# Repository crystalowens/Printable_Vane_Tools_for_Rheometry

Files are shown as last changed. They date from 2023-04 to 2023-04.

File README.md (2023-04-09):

# Printable Vane Tools for Rheometry
Design tools and guidelines for using 3D printable rheometry devices

Please give credit for tools to the appropriate references: 

1\) Improved rheometry of yield stress fluids using bespoke fractal 3D printed vanes  
&emsp;Journal of Rheology 64, 643 (2020); https://doi.org/10.1122/1.5132340   
&emsp;Crystal E. Owens, A. John Hart, and Gareth H. McKinley 

    * for most tools 
    * for the coupling to the rheometer
    * for the cup that mounts to the flat peltier base

2\) Computational rheometry of yielding and viscoplastic flow in vane-and-cup rheometer fixtures  
&emsp;Journal of Non-Newtonian Fluid Mechanics 37, 104857 (2022); https://doi.org/10.1016/j.jnnfm.2022.104857  
&emsp;Emad Chaparian, Crystal E. Owens, and Gareth H. McKinley

    * for the 8-arm tool design 

3\) Time-resolved rheometry of coarsening foams using three-dimensionally printed fractal vanes   
&emsp;Physics of Fluids 34, 113108 (2022); https://doi.org/10.1063/5.0119944  
&emsp;Igor M. Carraretto, Crystal E. Owens, and Gareth H. McKinley

    * for the foaming cup
    * for the cup that slides into the peltier jacket

# Getting started 

See our pdf guide file for general instructions, and see our relevant papers for more detailed instructions  

# Tools included 

In this repository find .stl files for 
* Vanes for DHR-style and AR-style rheometers (tested with DHR-3, AR-G2)  
    * 8-arm fractal vane 
    * 12-arm fractal vane
    * 24-arm fractal vane
    * 4-arm fractal vane 
  
* Cups for DHR-style and AR-style rheometers (tested with DHR-3, AR-G2)
  * Cup base to mount to a flat peltier base, which then accepts a second part, either a cup with a bottom (for viscous fluids) or a cup without a bottom (for yield stress fluids, easier to clean)  
  * One-part cup to slide into a DHR-style peltier jacket
  * Cup for creating foam in-situ, using the 3D printed cup in addition to an airstone and airflow. This is provided in a directly-printable .form file for a Form2 or Form3 printer and also requires printing of the cup base to mount to the rheometer. 
  
* Vanes for ARES-style rheometers (tested with ARES-G2, original ARES)
  * 12-arm fractal for fitting to an ARES coupling. The fitting has been verified but the concentricity of rotation has not 

# Want another tool? 

Please contact me via linkedin or email or open an "issue" on this repository to start a discussion 

# Made your own version of our tools that you want to share? 

Please do! Send me a digital copy and information about why you want to share it and I will add it to our file list

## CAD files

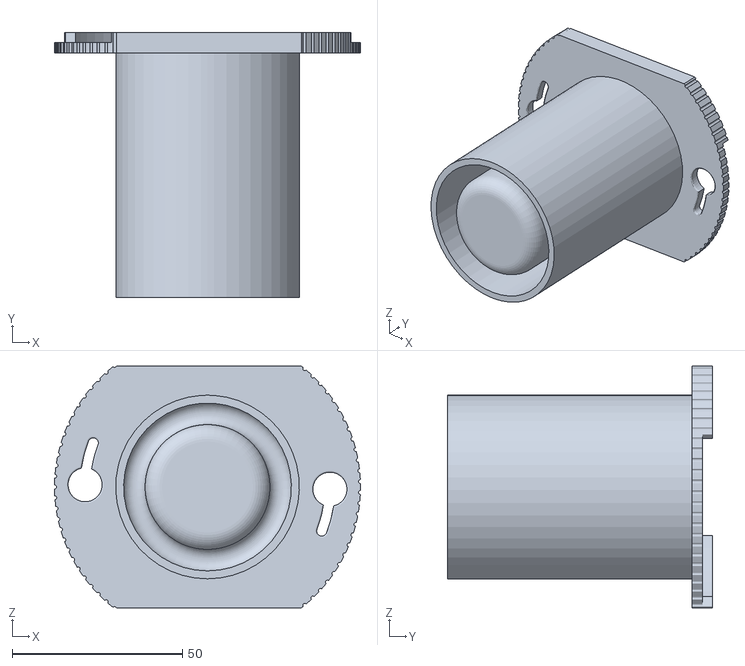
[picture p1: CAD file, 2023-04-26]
Part STL files/Cup - for DHR Peltier Jacket, 30mm ID (one part).STL
90.0 x 78.0 x 71.0

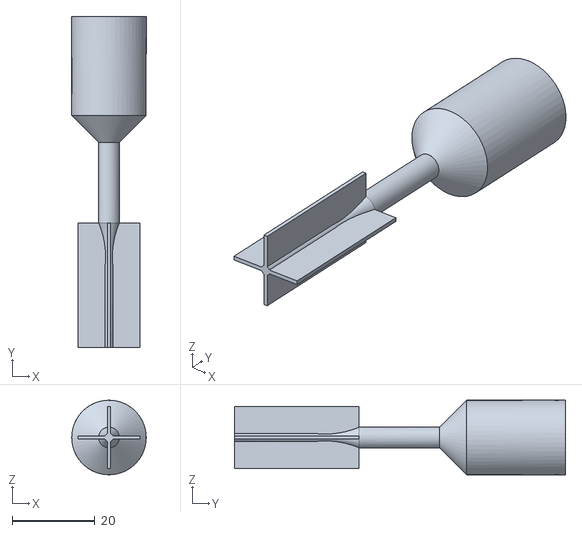
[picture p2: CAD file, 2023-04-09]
Part STL files/Vane - 4 arm - for DHR.stl
18.0 x 79.8 x 18.0

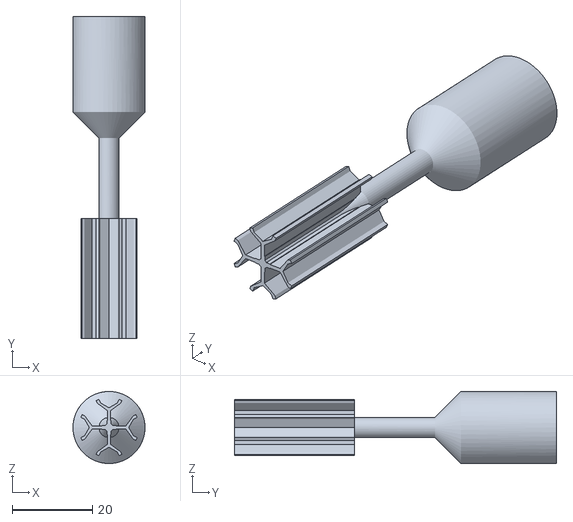
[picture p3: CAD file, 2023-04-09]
Part STL files/Vane - 8 arm fractal (0.8mm thick) - for DHR.STL
18.0 x 80.3 x 18.0

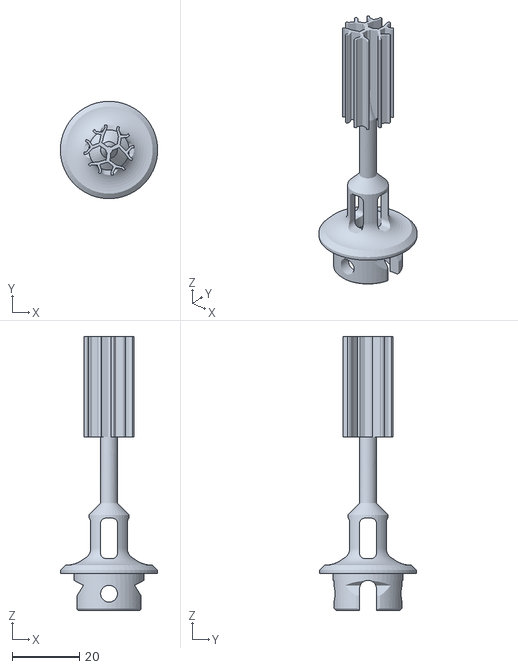
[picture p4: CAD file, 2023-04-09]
Part STL files/Vane - 12 point fractal - for ARES-G2.stl
29.0 x 29.0 x 81.6

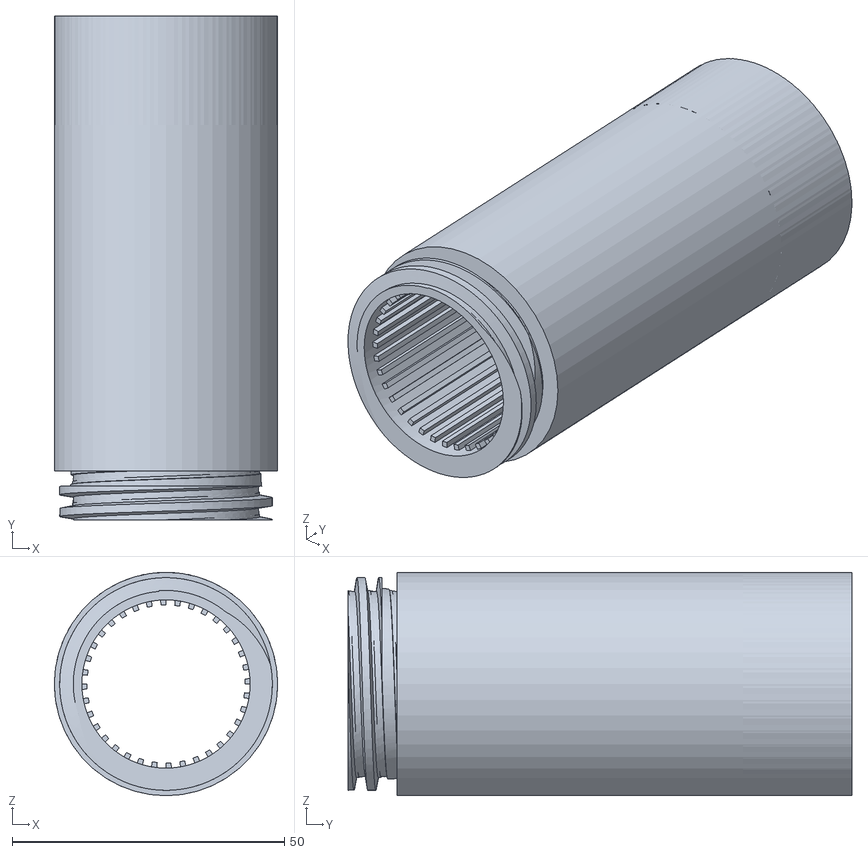
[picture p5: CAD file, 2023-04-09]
Part STL files/Cup without bottom plane - for DHR FLAT Peltier (part 2 of 2), 30mm ID.STL
41.0 x 92.5 x 41.0

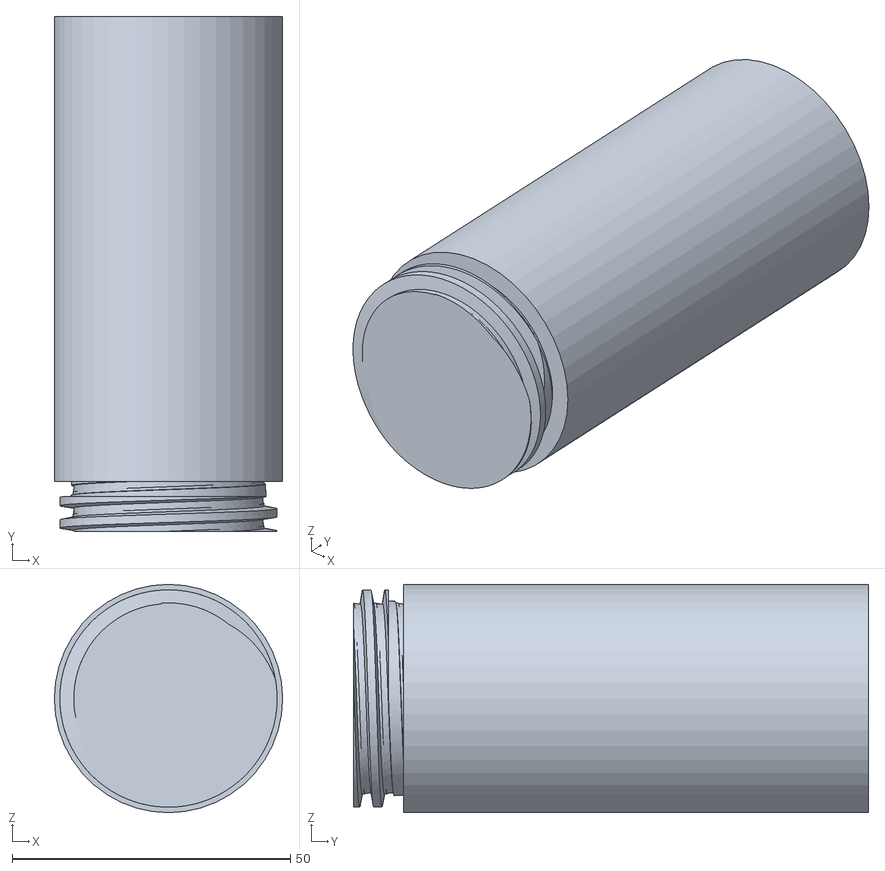
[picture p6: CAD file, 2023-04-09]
Part STL files/Cup - for DHR FLAT Peltier (part 2 of 2), 30mm ID.STL
41.0 x 92.5 x 41.0

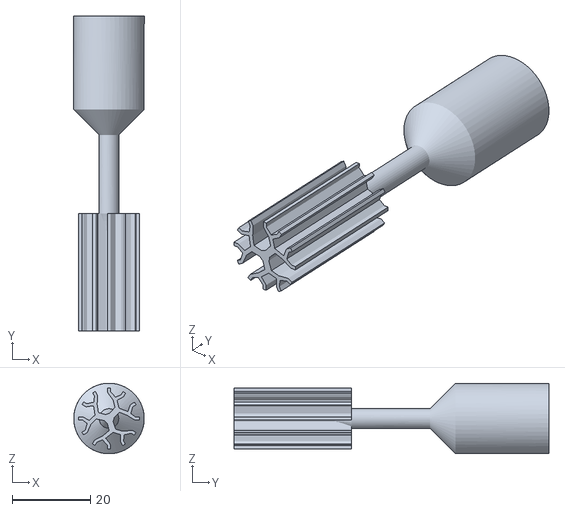
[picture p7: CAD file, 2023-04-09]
Part STL files/Vane - 12 point fractal (0.8mm thick) - for DHR.stl
18.0 x 80.3 x 18.0

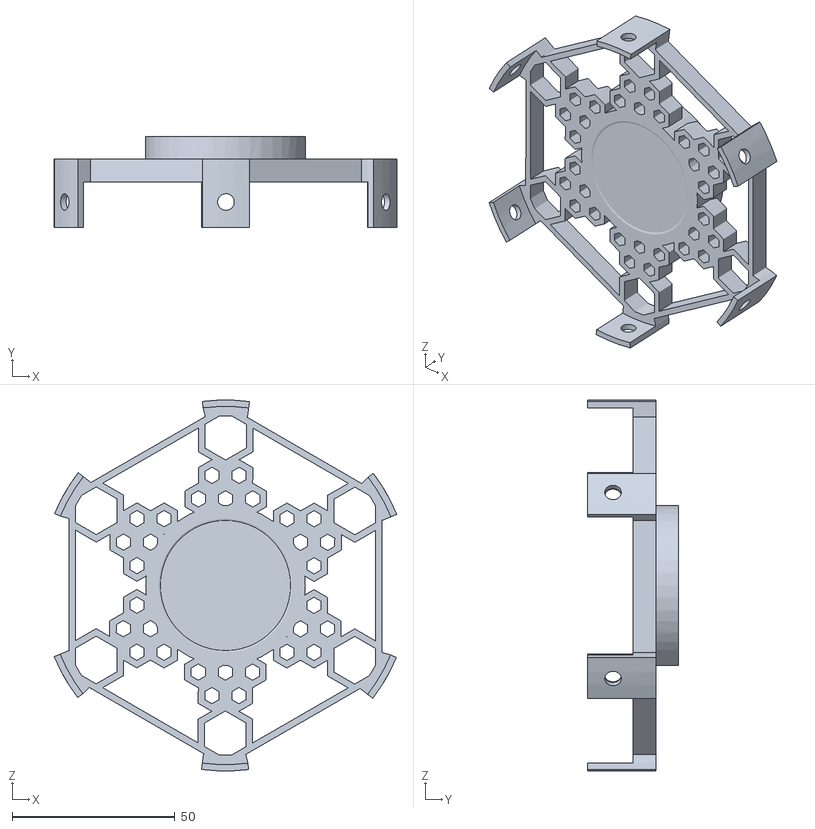
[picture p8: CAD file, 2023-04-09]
Part STL files/Cup base - for DHR FLAT peltier (part 1 of 2).STL
105.2 x 28.0 x 113.9

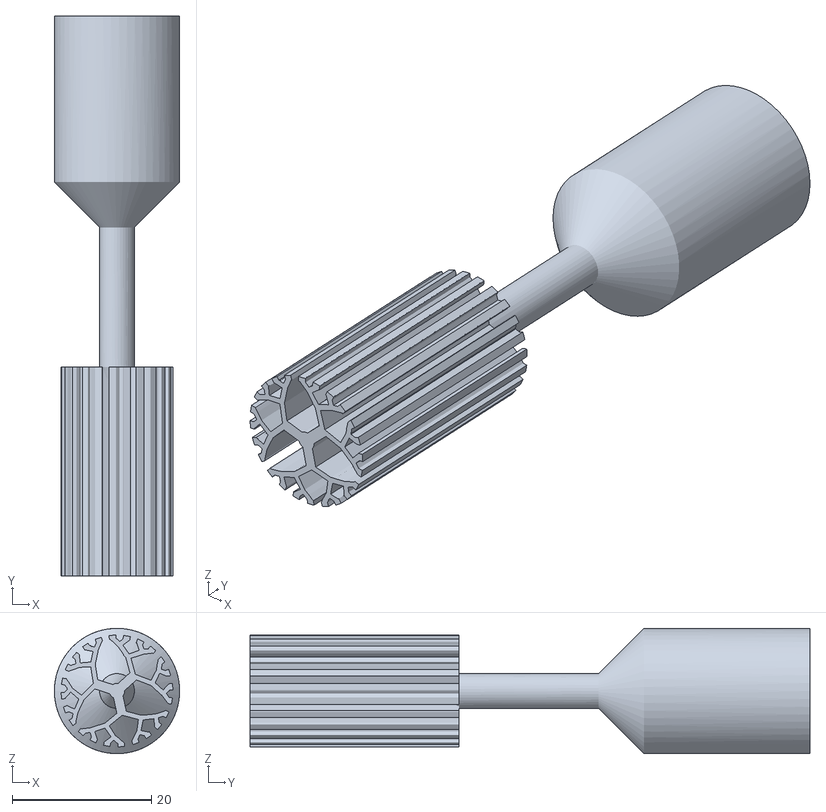
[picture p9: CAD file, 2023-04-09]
Part STL files/Vane - 24 point fractal (0.92mm thick) - for DHR.stl
18.0 x 80.3 x 18.0

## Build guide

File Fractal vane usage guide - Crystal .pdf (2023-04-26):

## The NNF Guide to

# Using 3D Printed Rheometer Tools

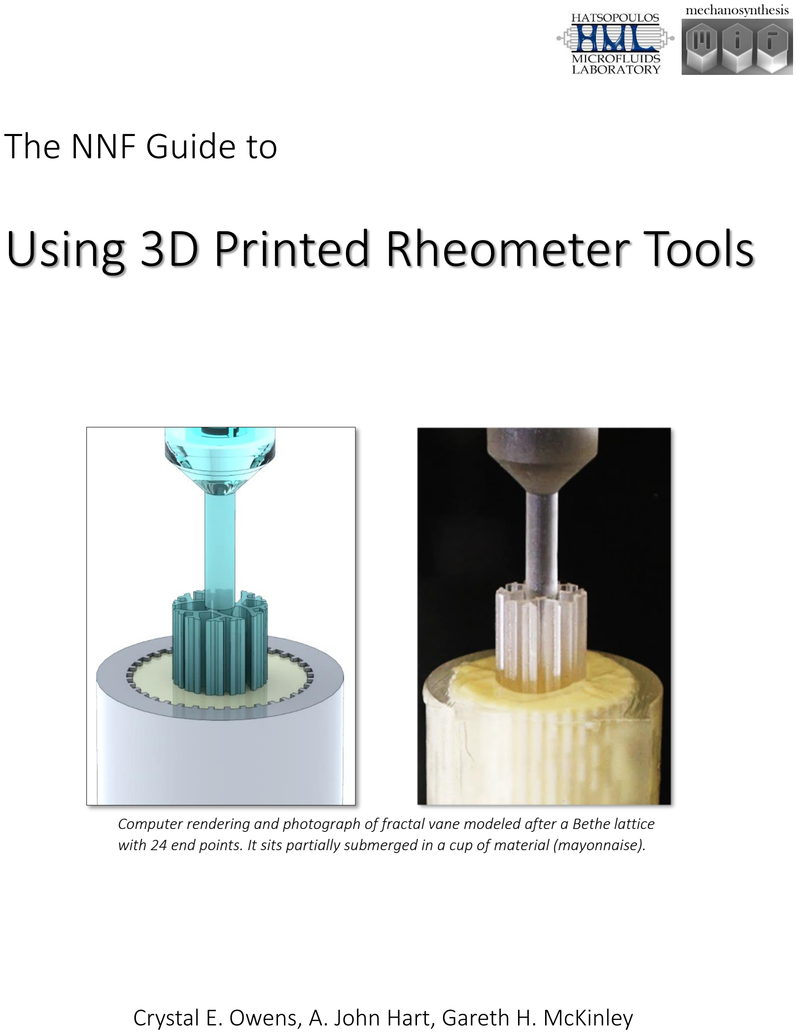
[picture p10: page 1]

mechanosynthesis

Computer rendering and photograph of fractal vane modeled after a Bethe lattice with 24 end points. It sits partially submerged in a cup of material (mayonnaise).

Crystal E. Owens, A. John Hart, Gareth H. McKinley

# 1. Design choice

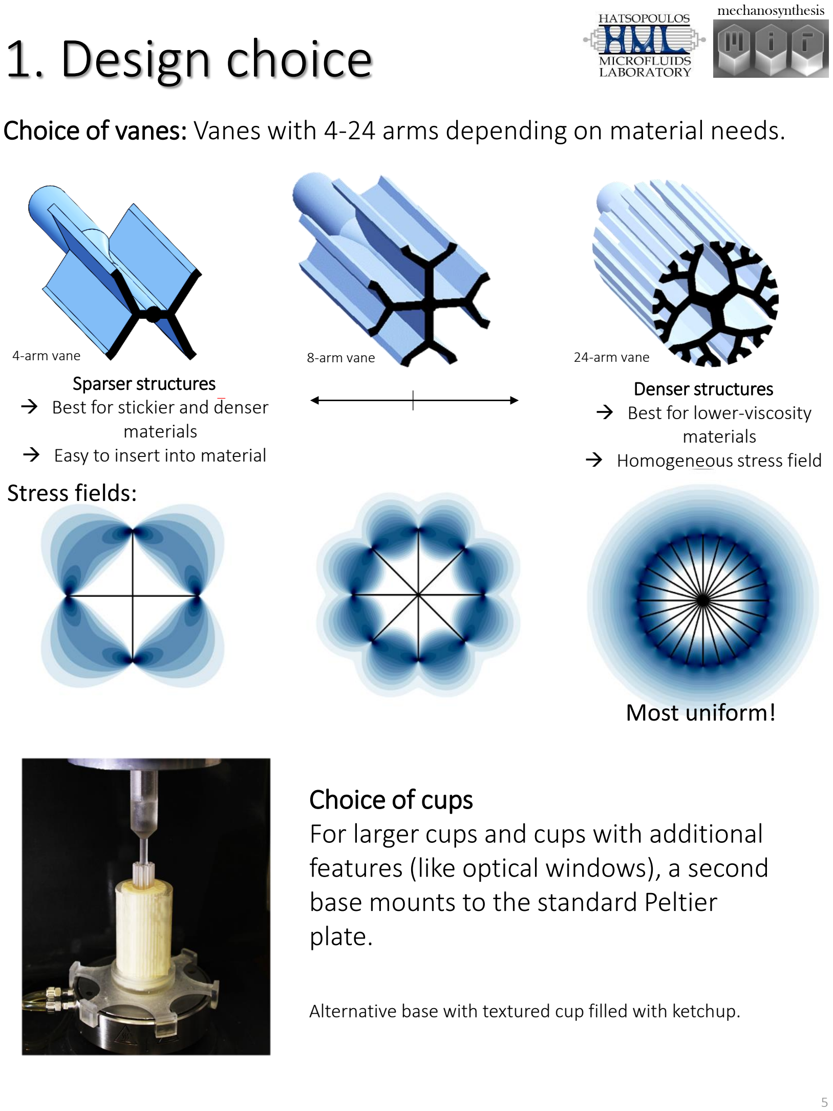
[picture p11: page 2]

Choice of vanes: Vanes with 4-24 arms depending on material needs.

Choice of cups
For larger cups and cups with additional features (like optical windows), a second base mounts to the standard Peltier plate.

Alternative base with textured cup filled with ketchup.

Sparser structures
→ Best for stickier and denser materials
→ Easy to insert into material

Denser structures
→ Best for lower-viscosity materials
→ Homogeneous stress field
4-arm vane | 8-arm vane | 24-arm vane

Stress fields:

Most uniform!

# 2. About the Parts

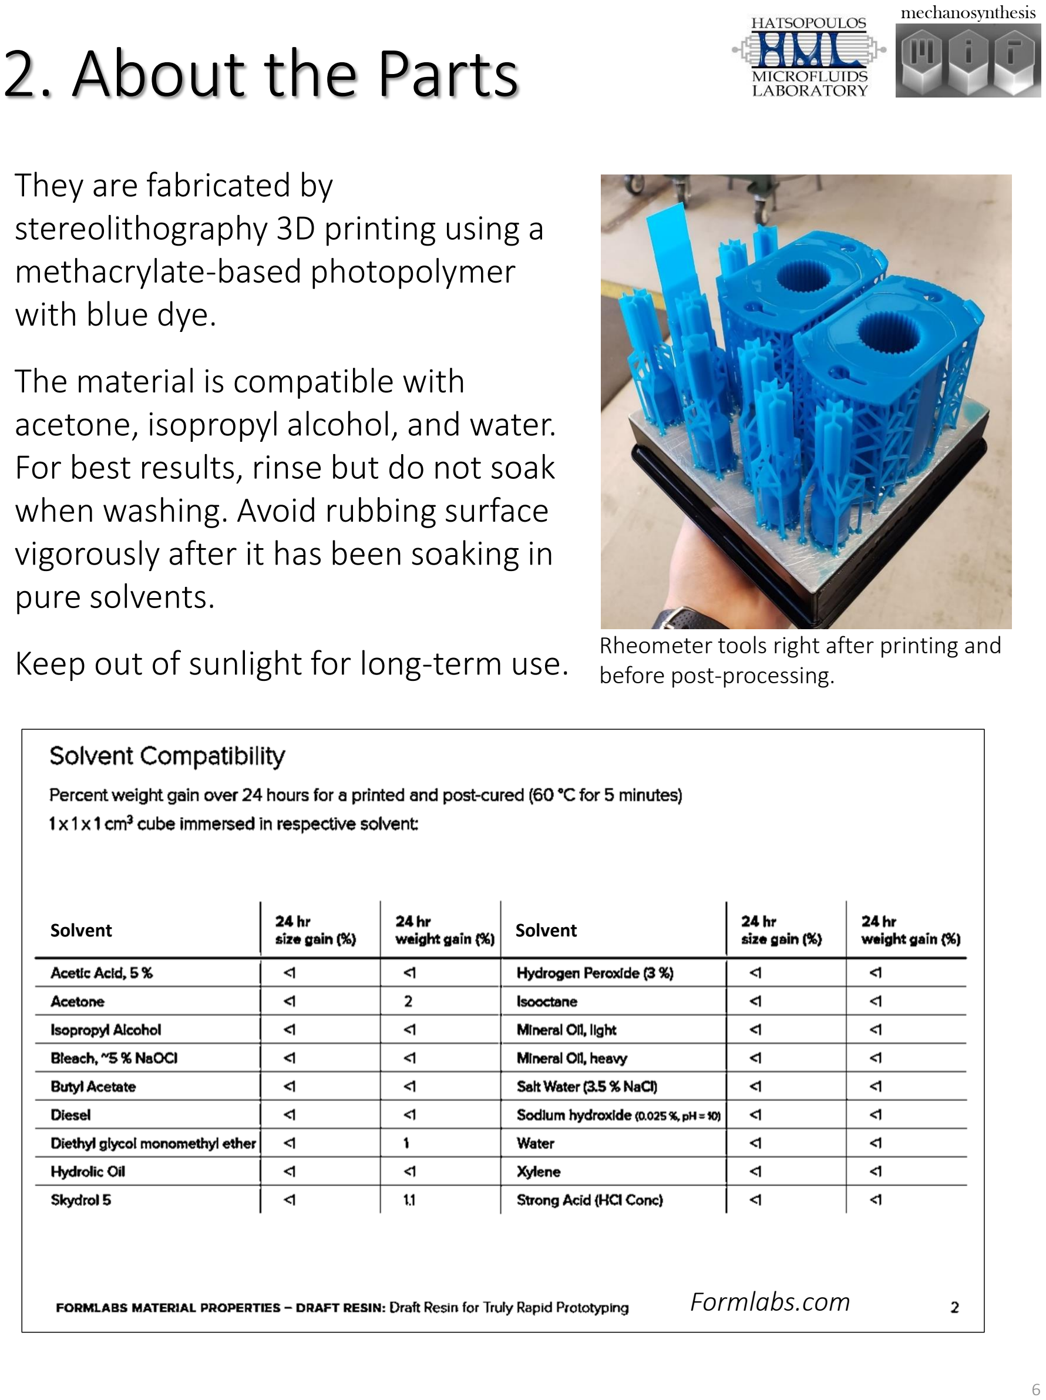
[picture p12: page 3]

They are fabricated by
stereolithography 3D printing using a methacrylate-based photopolymer with blue dye.

The material is compatible with acetone, isopropyl alcohol, and water. For best results, rinse but do not soak when washing. Avoid rubbing surface vigorously after it has been soaking in pure solvents.

Keep out of sunlight for long-term use.

Rheometer tools right after printing and before post-processing.

Formlabs.com

Solvent | Solvent

## Textured Cup

# 3. Getting Started

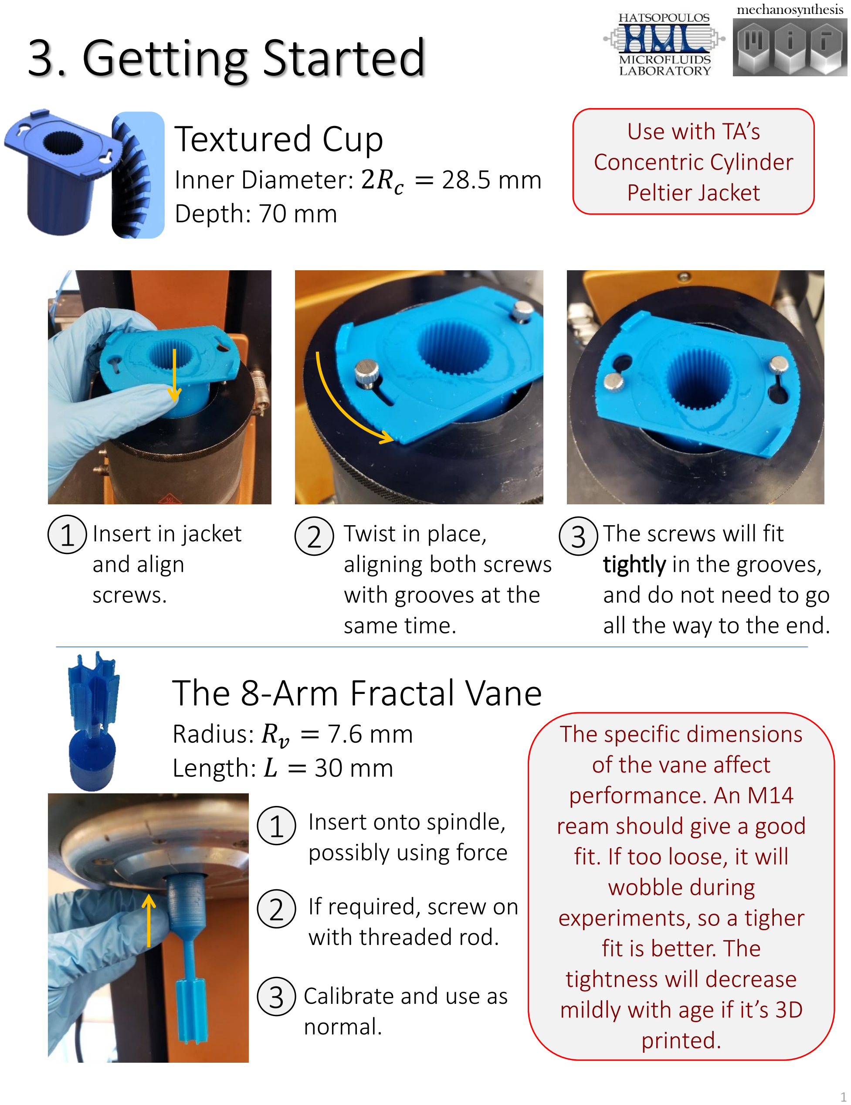
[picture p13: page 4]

1 Insert in jacket | 2 | 3
and align
screws.

Twist in place,
aligning both screws
with grooves at the
same time.

The screws will fit
tightly in the grooves,
and do not need to go
all the way to the end.

Inner Diameter: 2Rc = 28.5 mm Depth: 70 mm

1

2

3

Insert onto spindle,
possibly using force

If required, screw on
with threaded rod.

Calibrate and use as
normal.

## The 8-Arm Fractal Vane

Radius: Rv = 7.6 mm
Length: L = 30 mm

The specific dimensions
of the vane affect
performance. An M14
ream should give a good
fit. If too loose, it will wobble during
experiments, so a tigher
fit is better. The
tightness will decrease
mildly with age if it’s 3D printed.

Use with TA’s
Concentric Cylinder
Peltier Jacket

# 4. Sample Loading

## Minimizing end effects and boundary layers with vanes

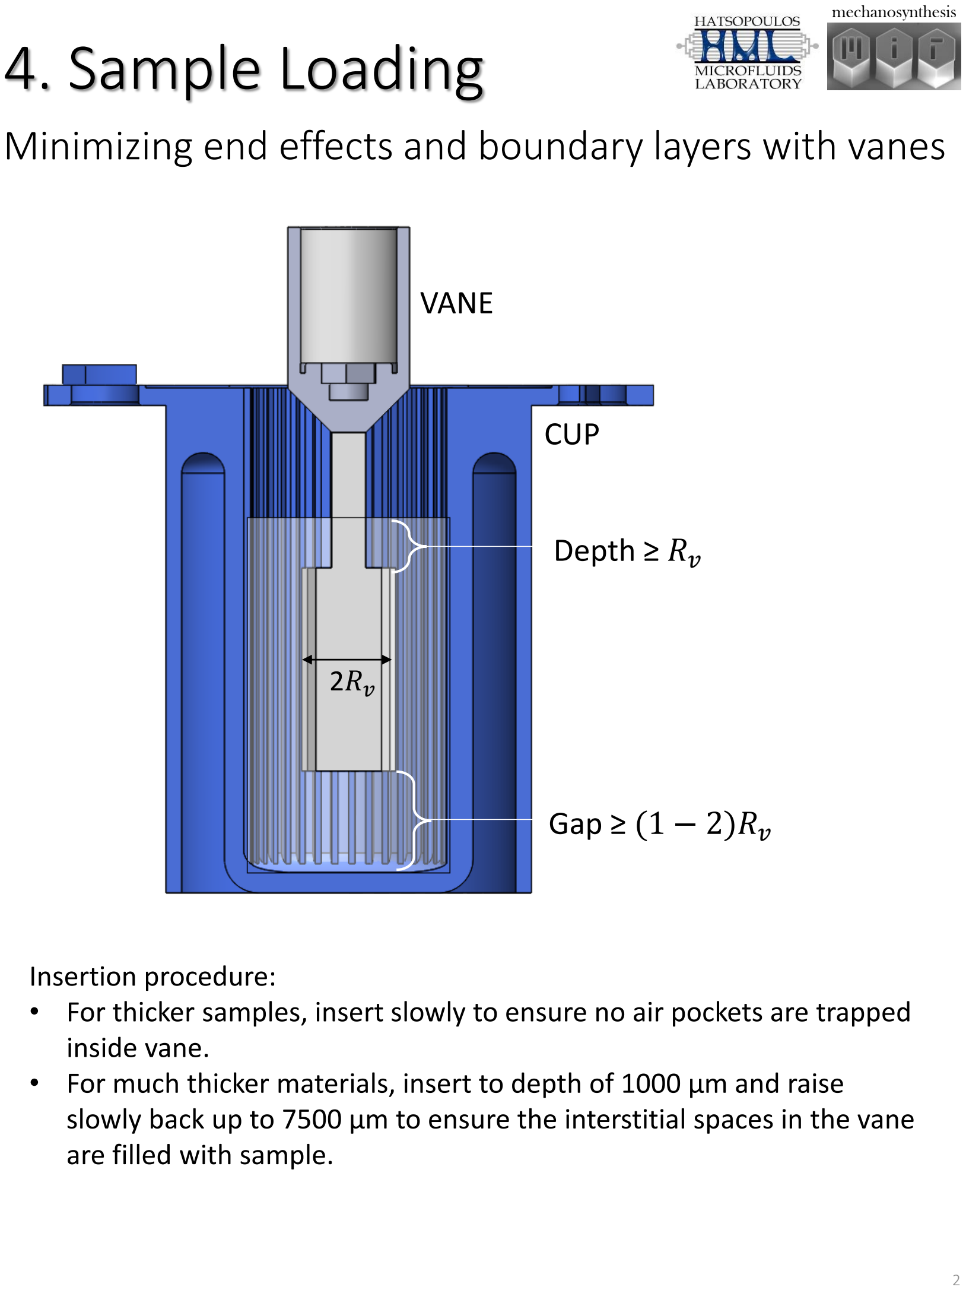
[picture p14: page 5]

Insertion procedure:
- For thicker samples, insert slowly to ensure no air pockets are trapped inside vane.
- For much thicker materials, insert to depth of 1000 µm and raise slowly back up to 7500 µm to ensure the interstitial spaces in the vane are filled with sample.

Depth ≥ Rv

Gap ≥ (1 − 2)Rv

2Rv

CUP

VANE

# 5. After use: Cleaning Tips

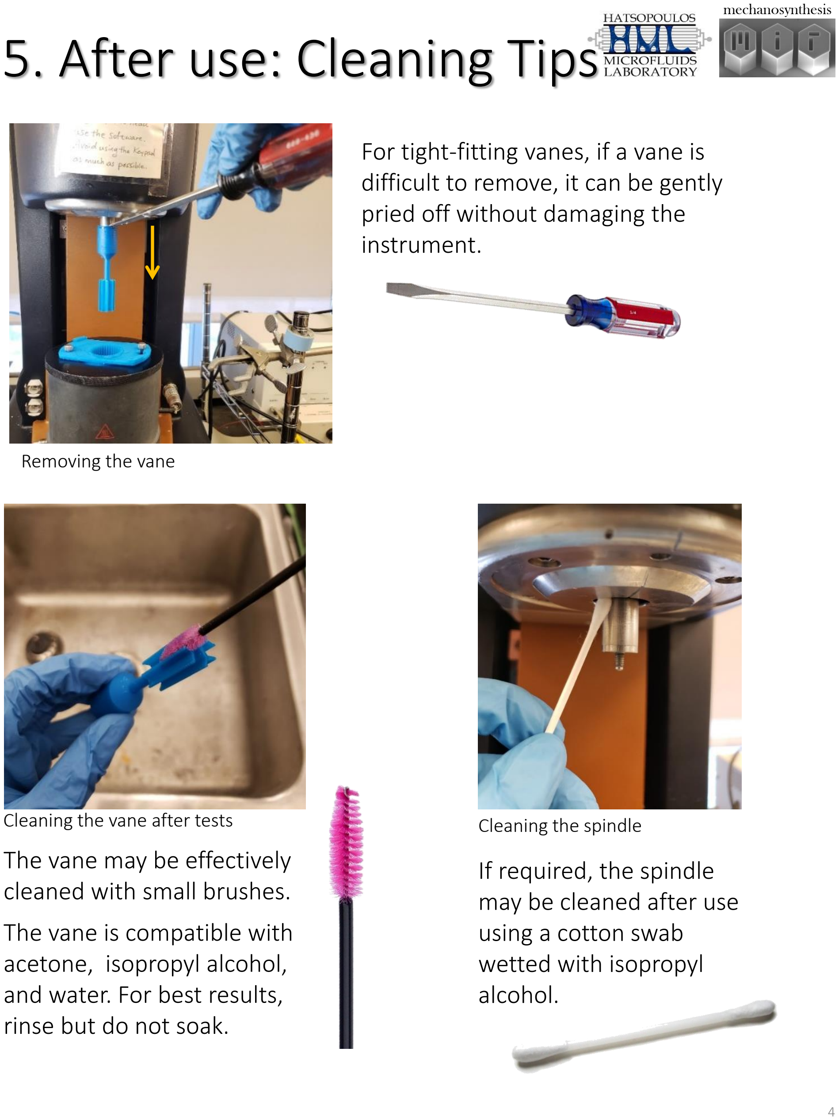
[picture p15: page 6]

For tight-fitting vanes, if a vane is difficult to remove, it can be gently pried off without damaging the instrument.

If required, the spindle
may be cleaned after use
using a cotton swab
wetted with isopropyl
alcohol.

The vane may be effectively cleaned with small brushes. The vane is compatible with acetone, isopropyl alcohol, and water. For best results, rinse but do not soak.

Removing the vane

Cleaning the vane after tests | Cleaning the spindle

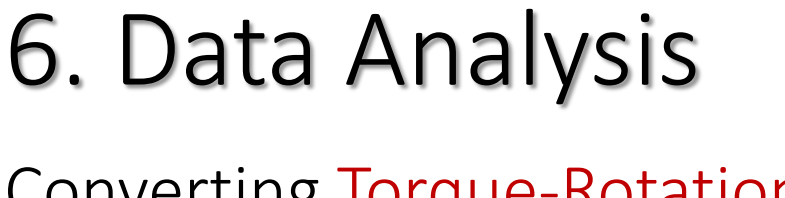
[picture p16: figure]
6. Data Analysis

## Variables [and units]:

N number of vane arms | Rv vane radius [m]
L vane length [m] | Rc cup inner radius [m]
Ω rotation [rad/s] | γሶ shear rate [s⁻¹ ]
M Torque [N-m] | σ shear stress [Pa]

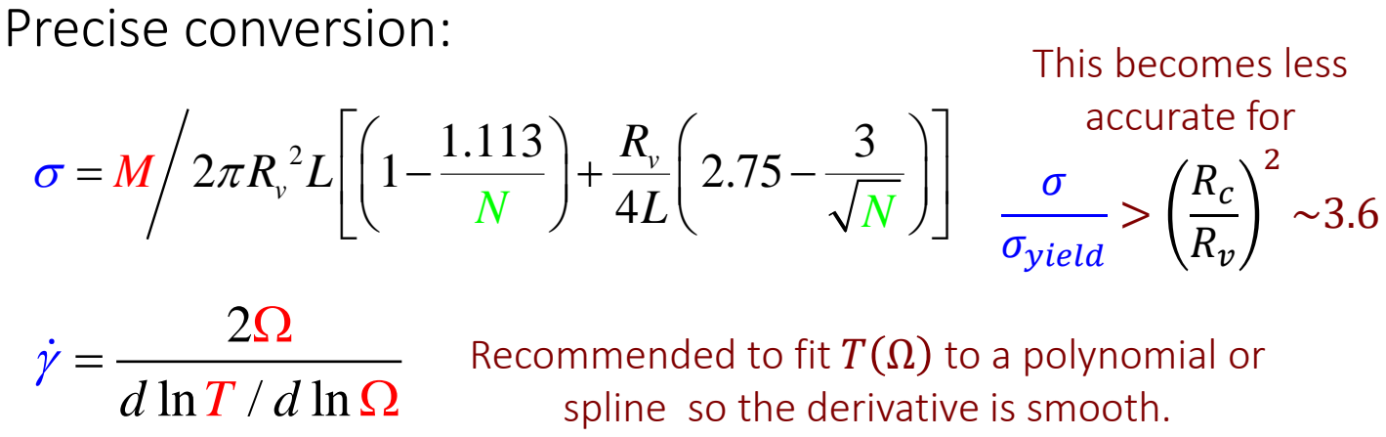
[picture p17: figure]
Precise conversion:; spline so the derivative is smooth.; This becomes less accurate for; σyield

## Approximate fitting (~10-300% error):

## Converting Torque-Rotation to Stress-Shear Rate

Recommended to fit T Ω to a polynomial or

σ ≈ 95, 000M

γ ≈ 9Ω

Key References:
[1] C. Atkinson, J.D. Sherwood. The torque on a rotating n-bladed vane in a Newtonian fluid or linear elastic medium. Proc. R. Soc. Lond. A (1992).
[2] C. E. Owens, T. Narayanan, A. J. Hart, G. H. McKinley. Additively manufactured vanes with modified geometries for measurements of yield-stress fluids. Society of Rheology (2018).

Calculated for 8-arm vane

~10-300% error. Estimated from one Carbopol material.
